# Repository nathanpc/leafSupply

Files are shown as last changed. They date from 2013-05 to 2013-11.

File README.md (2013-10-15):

leafSupply

## More Information

For more information about how this project evolved you should check out the [project blog](http://electronics.dreamintech.net/).

## Credits

This project is the work of:

 - [Nathan Campos](http://about.me/nathanpc): Everything involved with the electronics part.
 - [Narek Babajanyan](https://twitter.com/narekb): Awesome leaf icon.

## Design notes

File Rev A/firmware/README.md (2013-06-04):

# leafSupply Firmware

This is the leafSupply firmware for the [TI MSP430G2553](http://www.ti.com/lit/ds/symlink/msp430g2553.pdf) microcontroller.

## Pins

TODO: Put a pin list right here.

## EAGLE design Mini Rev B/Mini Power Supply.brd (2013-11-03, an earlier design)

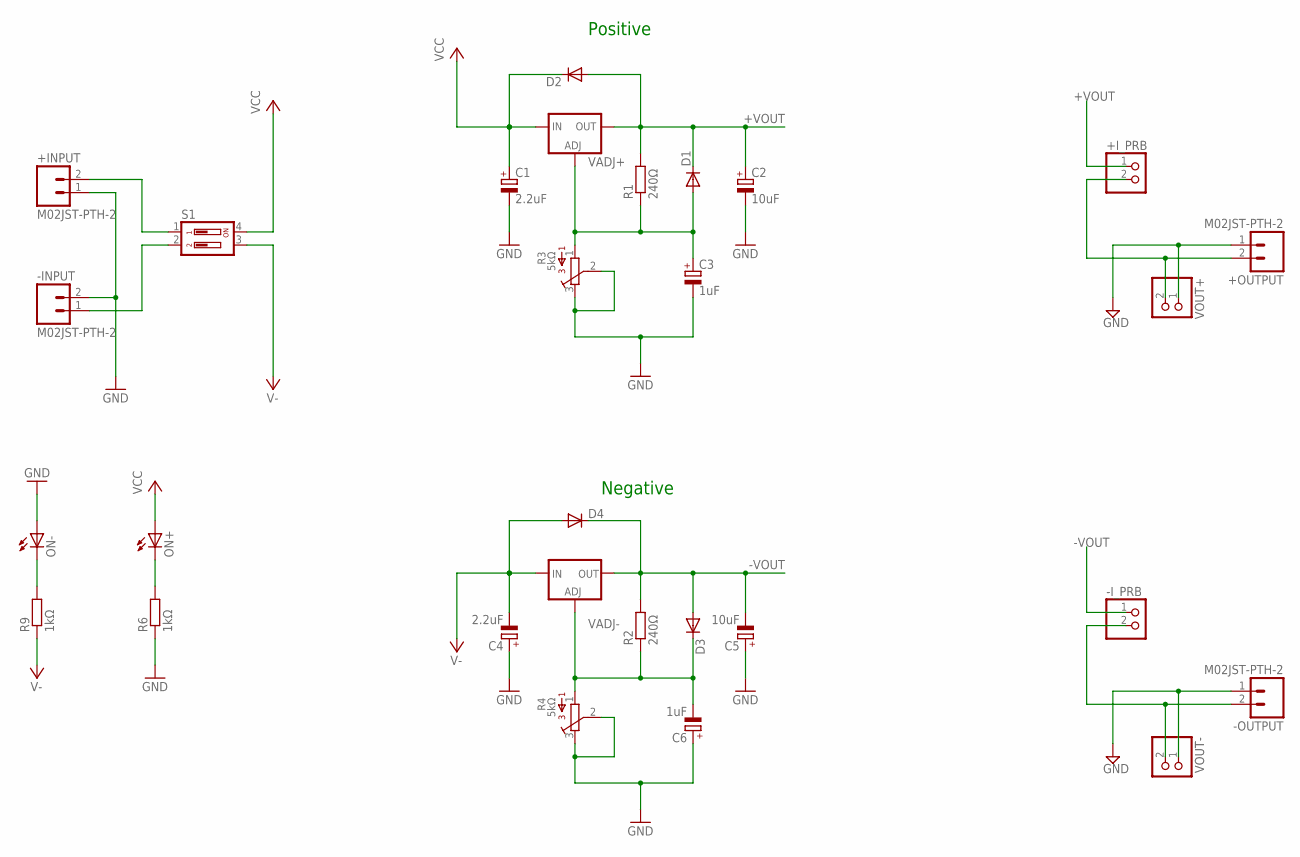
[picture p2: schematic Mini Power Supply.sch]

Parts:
+INPUT: M02JST-PTH-2; JST-2-PTH
+I_PRB: PINHD-1X2; 1X02
+OUTPUT: M02JST-PTH-2; JST-2-PTH
-INPUT: M02JST-PTH-2; JST-2-PTH
-I_PRB: PINHD-1X2; 1X02
-OUTPUT: M02JST-PTH-2; JST-2-PTH
C1, C4: 2.2uF; E2,5-6
C2, C5: 10uF; E2,5-6
C3, C6: 1uF; E2,5-6
D1, D2, D3, D4: 1N4148DO35-7; DO35-7
ON+: LEDSQR2X5; LED2X5
ON-: LEDSQR2X5; LED2X5
R1, R2: 240Ω; 0207/10
R3, R4: 5kΩ; 3386U
R6, R9: 1kΩ; 0207/10
S1: DIP02YL
VADJ+: LM317L; 317L
VADJ-: LM337L; 337L
VOUT+: PINHD-1X2; 1X02
VOUT-: PINHD-1X2; 1X02

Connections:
+VOUT: +I_PRB.1, C2.+, D1.C, D2.A, R1.2, VADJ+.2 (OUT)
-VOUT: -I_PRB.1, C5.-, D3.A, D4.C, R2.2, VADJ-.OUT
GND: +INPUT.1, +OUTPUT.1, -INPUT.2, -OUTPUT.1, C1.-, C2.-, C3.-, C4.+, C5.+, C6.+, ON-.A, R3.2, R3.3, R4.2, R4.3, R6.1, VOUT+.1, VOUT-.1
unnamed: C6.-, D3.C, R2.1, R4.1, VADJ-.ADJ
unnamed: +INPUT.2, S1.1
unnamed: C3.+, D1.A, R1.1, R3.1, VADJ+.1 (ADJ)
unnamed: ON-.K (C), R9.2
unnamed: -INPUT.1, S1.2
unnamed: ON+.K (C), R6.2
unnamed: +I_PRB.2, +OUTPUT.2, VOUT+.2
unnamed: -I_PRB.2, -OUTPUT.2, VOUT-.2
V-: C4.-, D4.A, R9.1, S1.3, VADJ-.IN
VCC: C1.+, D2.C, ON+.A, S1.4, VADJ+.3 (IN)

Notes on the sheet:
Positive
Negative

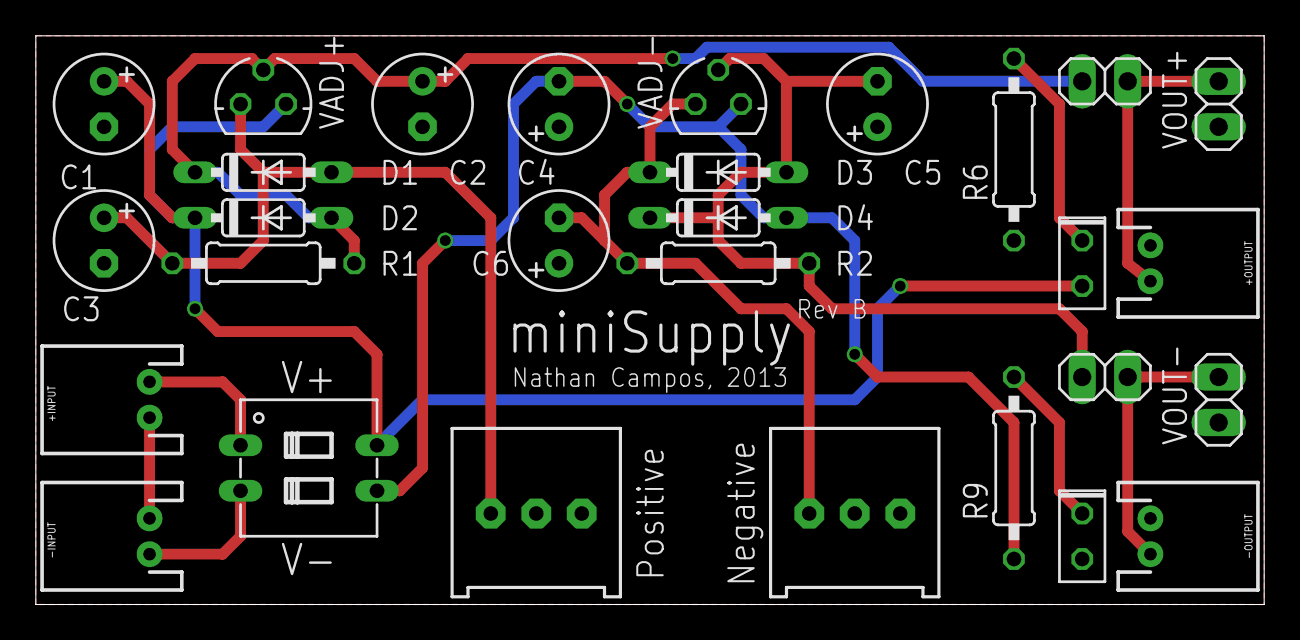
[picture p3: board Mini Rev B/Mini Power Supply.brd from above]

Board: 4 copper layers, 68.6 x 31.8 mm, 29 parts (0 on the bottom side), 13 nets.

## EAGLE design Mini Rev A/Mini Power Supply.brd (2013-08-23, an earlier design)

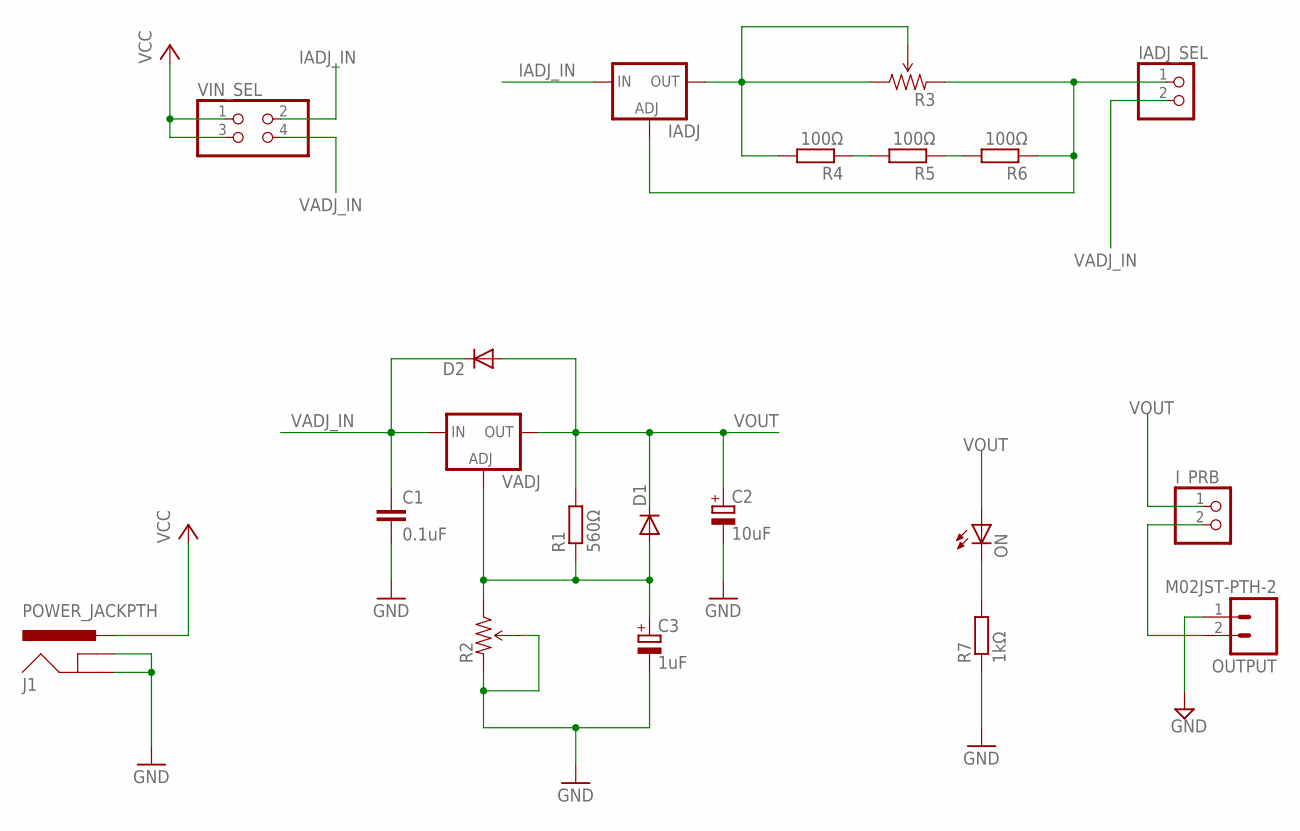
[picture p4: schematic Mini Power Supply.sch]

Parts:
C1: 0.1uF; C0805
C2: 10uF; E2,5-6
C3: 1uF; E2,5-6
D1, D2: DIODE-SOD323-W; SOD323-W
IADJ: LM317TS; 317TS
IADJ_SEL: PINHD-1X2; 1X02
I_PRB: PINHD-1X2; 1X02
J1: POWER_JACKPTH; POWER_JACK_PTH
ON: LEDCHIPLED_1206; CHIPLED_1206
OUTPUT: M02JST-PTH-2; JST-2-PTH
R1: 560Ω; R0805
R2, R3: TRIMPOT-PTH-KNOB; 3386U
R4, R5, R6: 100Ω; R0805
R7: 1kΩ; R0805
VADJ: LM317TS; 317TS
VIN_SEL: PINHD-2X2; 2X02

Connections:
GND: C1.2, C2.-, C3.-, J1.GND, J1.GNDBREAK, OUTPUT.1, R2.2 (WIPER), R2.3 (CW), R7.1
IADJ_IN: IADJ.3 (IN), VIN_SEL.2
unnamed: IADJ.2 (OUT), R3.1 (CCW), R3.2 (WIPER), R4.2
unnamed: R4.1, R5.2
unnamed: C3.+, D1.A, R1.1, R2.1 (CCW), VADJ.1 (ADJ)
unnamed: IADJ.1 (ADJ), IADJ_SEL.1, R3.3 (CW), R6.1
unnamed: R5.1, R6.2
unnamed: ON.C, R7.2
unnamed: I_PRB.2, OUTPUT.2
VADJ_IN: C1.1, D2.C, IADJ_SEL.2, VADJ.3 (IN), VIN_SEL.4
VCC: J1.PWR, VIN_SEL.1, VIN_SEL.3
VOUT: C2.+, D1.C, D2.A, I_PRB.1, ON.A, R1.2, VADJ.2 (OUT)

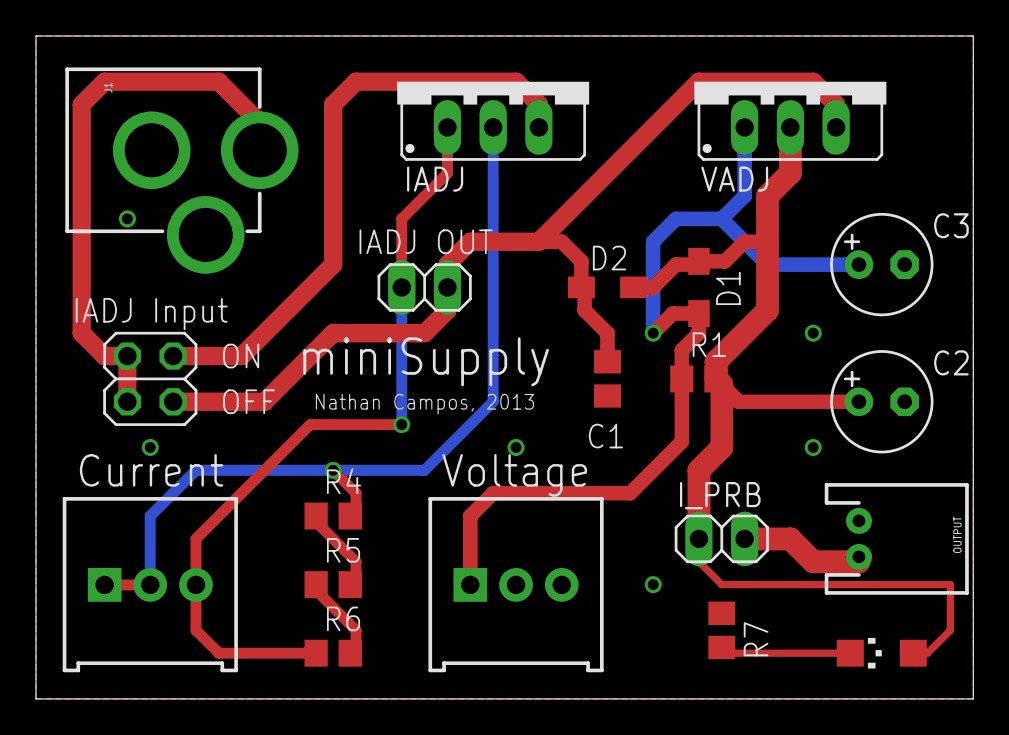
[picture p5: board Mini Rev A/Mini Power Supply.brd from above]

Board: 2 copper layers, 52.1 x 36.8 mm, 20 parts (0 on the bottom side), 12 nets.

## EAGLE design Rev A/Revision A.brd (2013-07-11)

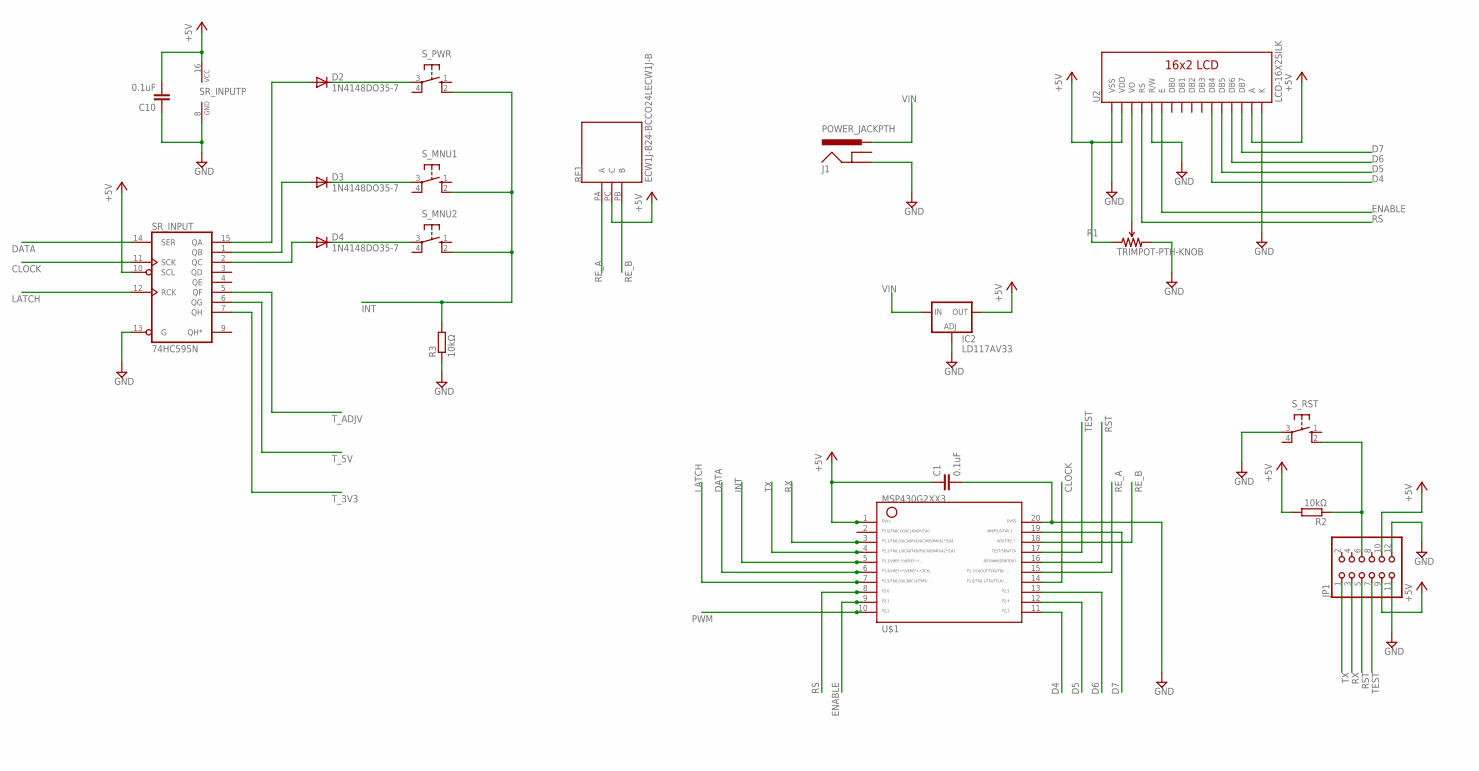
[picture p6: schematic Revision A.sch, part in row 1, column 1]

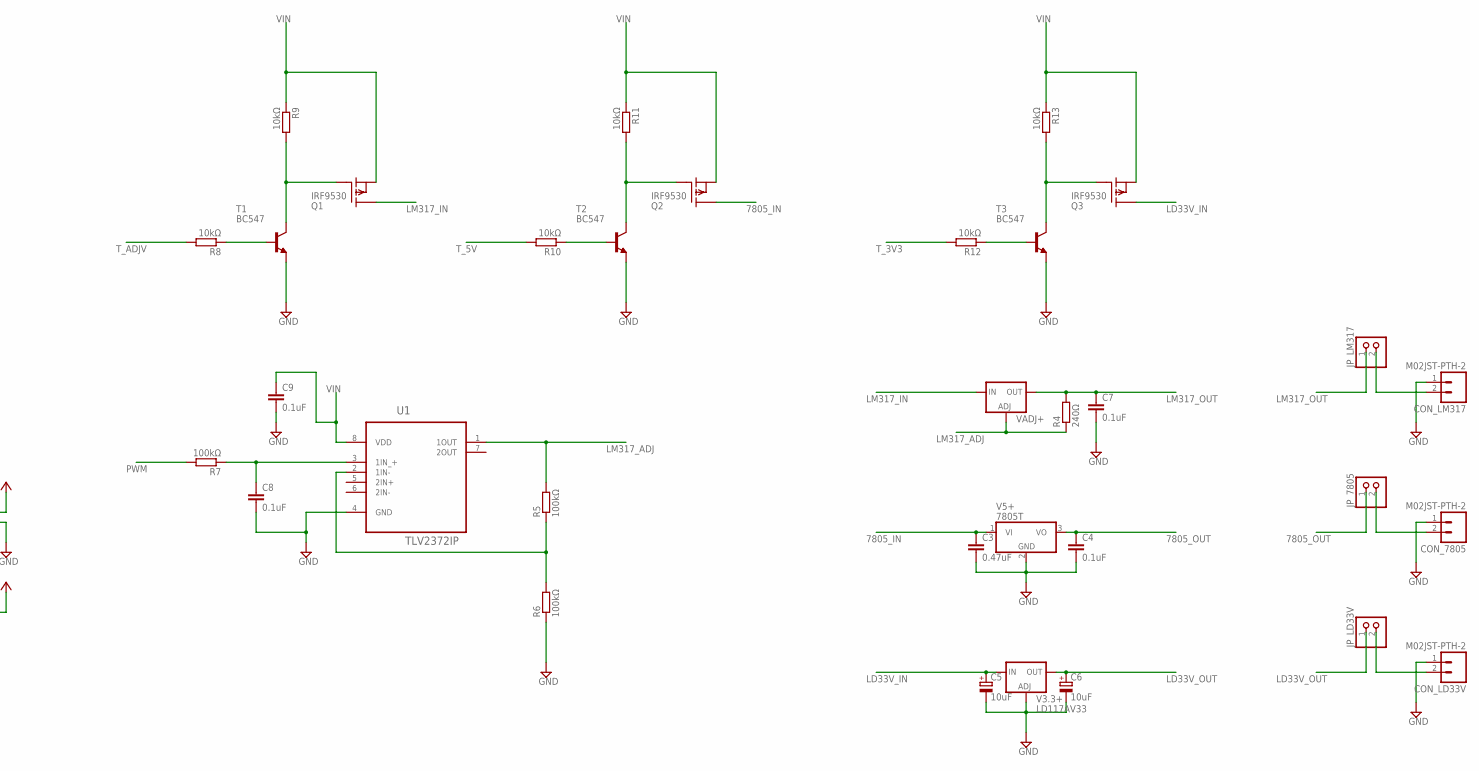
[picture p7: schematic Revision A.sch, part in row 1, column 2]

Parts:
C1, C4, C7, C8, C9, C10: 0.1uF; C025-025X050
C3: 0.47uF; C025-025X050
C5, C6: 10uF; E2,5-6
CON_7805: M02JST-PTH-2; JST-2-PTH
CON_LD33V: M02JST-PTH-2; JST-2-PTH
CON_LM317: M02JST-PTH-2; JST-2-PTH
D2, D3, D4: 1N4148DO35-7; DO35-7
IC2: LD117AV33; TO220L1
J1: POWER_JACKPTH; POWER_JACK_PTH
JP1: PINHD-2X6; 2X06
JP_7805: PINHD-1X2; 1X02
JP_LD33V: PINHD-1X2; 1X02
JP_LM317: PINHD-1X2; 1X02
Q1, Q2, Q3: IRF9530; TO220
R1: TRIMPOT-PTH-KNOB; 3386U
R2, R3, R8, R9, R10, R11, R12, R13: 10kΩ; 0207/10
R4: 240Ω; 0207/10
R5, R6, R7: 100kΩ; 0207/10
RE1: ECW1J-B24-BCCO24LECW1J-B; ECW1J-B
SR_INPUT: 74HC595N; DIL16
S_MNU1, S_MNU2: 10-XX; B3F-10XX
S_PWR: 10-XX; B3F-10XX
S_RST: 10-XX; B3F-10XX
T1, T2, T3: BC547; TO92
U1: TLV2372IP; DIP254P762X508-8
U2: LCD-16X2SILK; LCD-16X2
U$1: G2XX3---N20; N20
V3.3+: LD117AV33; TO220L1
V5+: 7805T; TO220H
VADJ+: LM317TL; 317TL

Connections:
7805_IN: C3.1, Q2.2 (D), V5+.1 (VI)
7805_OUT: C4.1, JP_7805.1, V5+.3 (VO)
+5V: C1.1, C10.2, IC2.2 (OUT), JP1.9, JP1.10, R1.1 (CCW), R2.2, RE1.PC (C), SR_INPUT.10 (SCL), SR_INPUT.16 (VCC), U2.2 (VDD), U2.15 (A), U$1.1
CLOCK: SR_INPUT.11 (SCK), U$1.14
D4: U2.11 (DB4), U$1.11
D5: U2.12 (DB5), U$1.12
D6: U2.13 (DB6), U$1.13
D7: U2.14 (DB7), U$1.19
DATA: SR_INPUT.14 (SER), U$1.6
ENABLE: U2.6 (E), U$1.9
GND: C1.2, C3.2, C4.2, C5.-, C6.-, C7.2, C8.2, C9.2, C10.1, CON_7805.1, CON_LD33V.1, CON_LM317.1, IC2.1 (ADJ), J1.GND, JP1.11, JP1.12, R1.3 (CW), R3.1, R6.1, SR_INPUT.8 (GND), SR_INPUT.13 (G), S_RST.3, T1.1 (E), T2.1 (E), T3.1 (E), U1.4 (GND), U2.1 (VSS), U2.5 (R/W), U2.16 (K), U$1.20, V3.3+.1 (ADJ), V5+.2 (GND)
INT: R3.2, S_MNU1.2 (S1), S_MNU2.2 (S1), S_PWR.2 (S1), U$1.5
LATCH: SR_INPUT.12 (RCK), U$1.7
LD33V_IN: C5.+, Q3.2 (D), V3.3+.3 (IN)
LD33V_OUT: C6.+, JP_LD33V.1, V3.3+.2 (OUT)
LM317_ADJ: R4.1, R5.2, U1.1 (1OUT), VADJ+.1 (ADJ)
LM317_IN: Q1.2 (D), VADJ+.3 (IN)
LM317_OUT: C7.1, JP_LM317.1, R4.2, VADJ+.2 (OUT)
unnamed: R1.2 (WIPER), U2.3 (VO)
unnamed: D2.C, S_PWR.3
unnamed: JP1.6, R2.1, S_RST.2 (S1)
unnamed: D3.C, S_MNU1.3
unnamed: D4.C, S_MNU2.3
unnamed: R5.1, R6.2, U1.2 (1IN-)
unnamed: C8.1, R7.1, U1.3 (1IN_+)
unnamed: R8.1, T1.2 (B)
unnamed: Q1.1 (G), R9.2, T1.3 (C)
unnamed: R10.1, T2.2 (B)
unnamed: D3.A, SR_INPUT.1 (QB)
unnamed: Q2.1 (G), R11.2, T2.3 (C)
unnamed: R12.1, T3.2 (B)
unnamed: Q3.1 (G), R13.2, T3.3 (C)
unnamed: CON_LM317.2, JP_LM317.2
unnamed: D4.A, SR_INPUT.2 (QC)
unnamed: D2.A, SR_INPUT.15 (QA)
unnamed: CON_7805.2, JP_7805.2
unnamed: CON_LD33V.2, JP_LD33V.2
PWM: R7.2, U$1.10
RE_A: RE1.PA (A), U$1.15
RE_B: RE1.PB (B), U$1.18
RS: U2.4 (RS), U$1.8
RST: JP1.5, U$1.16
RX: JP1.3, U$1.3
TEST: JP1.7, U$1.17
TX: JP1.1, U$1.4
T_3V3: R12.2, SR_INPUT.7 (QH)
T_5V: R10.2, SR_INPUT.6 (QG)
T_ADJV: R8.2, SR_INPUT.5 (QF)
VIN: C9.1, IC2.3 (IN), J1.PWR, Q1.3 (S), Q2.3 (S), Q3.3 (S), R9.1, R11.1, R13.1, U1.8 (VDD)

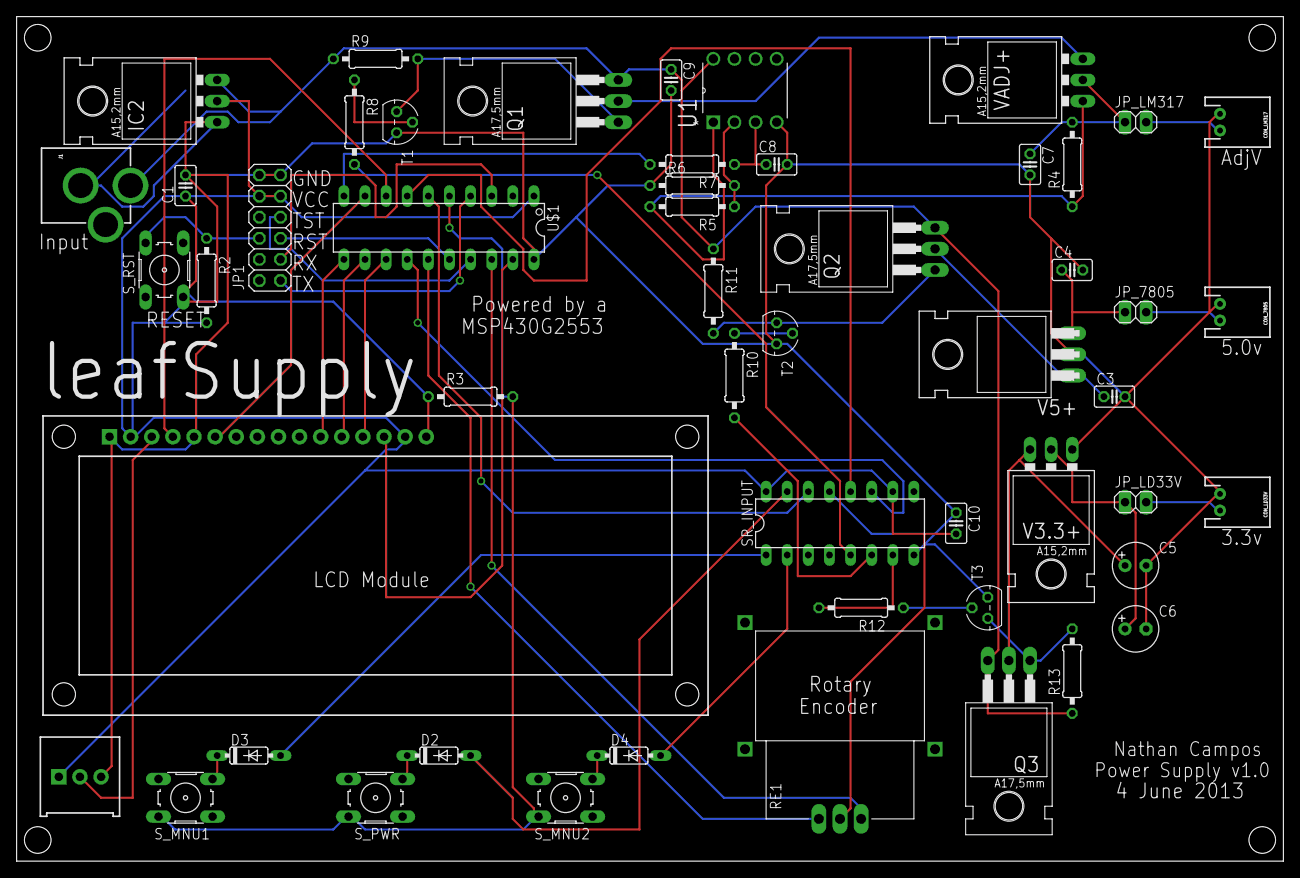
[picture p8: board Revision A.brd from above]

Board: 2 copper layers, 152.4 x 101.6 mm, 52 parts (0 on the bottom side), 49 nets.

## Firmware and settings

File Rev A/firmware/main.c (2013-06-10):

/**
 *	main.c
 *	leafSupply firmware for the MSP430G2553 microcontroller.
 *
 *	@author Nathan Campos <nathanpc@dreamintech.net>
 */

#include <msp430g2553.h>
#include <stdio.h>
#include <string.h>

#include "boolean.h"
#include "delay.h"
#include "bitio.h"
#include "ftoa.h"

#include "74HC595.h"
#include "rotary_encoder.h"
#include "HD44780.h"
#include "voltage_regulators.h"

// Interrupt pins.
#define BT_INT   BIT3
#define RE_A_INT BIT7
#define RE_B_INT BIT7

// Other pins.
#define PWM_PIN  BIT2

// Screen codes.
#define HOME_SCREEN 0

unsigned char shift_default_on = 0b11111000;

void print_voltage();
void print_vreg_state();
void print_screen(const unsigned int title);
void switch_vreg();

void setup_pwm();
void setup_interrupts();
void handle_re_rotation();
void handle_bt_press(unsigned int bt);

/**
 *	Where the magic starts.
 */
void main() {
	WDTCTL = WDTPW + WDTHOLD;  // Stop watchdog timer.
	//BCSCTL1 = CALBC1_1MHZ;     // Set range.
	//DCOCTL = CALDCO_1MHZ;      // SMCLK = DCO = 1MHz
	//BCSCTL2 &= ~(DIVS_3);

	// Setup the PWM stuff, ADC, and interrupts.
	setup_pwm();
	setup_interrupts();
	_BIS_SR(GIE);  // TODO: Do (LPMX + GIE) for low-power + interrupts.
	//__enable_interrupt();

	// Initialize the shift register driver.
	shift_register_setup();
	shift_out(shift_default_on);
	
	// Setup the LCD driver.
	lcd_init(TRUE, TRUE);

	// Initilalize the voltage regulator driver.
	vreg_init();

	// Go to the home screen.
	print_screen(HOME_SCREEN);

	while (TRUE) {
	}
}

/**
 *	Setup the interrupts stuff.
 */
void setup_interrupts() {
	P1DIR &= ~(BT_INT + RE_A_INT);
	P2DIR &= ~RE_B_INT;
	P2SEL &= ~RE_B_INT;  // Turn XOUT into P2.7

	P1IES &= ~(BT_INT + RE_A_INT);  // Set the interrupt to be from LOW to HIGH.
	P1IFG &= ~(BT_INT + RE_A_INT);  // P1.3 and P1.7 IFG cleared
	P1IE |= (BT_INT + RE_A_INT);    // Set P1.3 and P1.7 as interrupt.
}

/**
 *	Setup the PWM stuff.
 */
void setup_pwm() {
	P2DIR |= PWM_PIN;
	P2SEL |= PWM_PIN;      // Set P2.2 to TA1.1

	TA1CCR0  = 100 - 1;    // PWM period.
	TA1CCTL1 = OUTMOD_7;   // CCR1 Reset/Set.
	TA1CCR1  = 0;          // CCR1 PWM duty cycle.
	TA1CTL   = TASSEL_2 + MC_1;
}

/**
 *	Prints a "screen".
 *
 *	@param title The screen you want to display.
 */
void print_screen(const unsigned int title) {
	lcd_clear();

	switch (title) {
		case HOME_SCREEN:
			// Example:
			// +----------------+
			// |LM317       7.8V|
			// |             OFF|
			// +----------------+
			lcd_print(vregs.list[vregs.curr_onscreen], 0, 0);
			print_voltage();
			print_vreg_state();
			break;
	}
}

/**
 *	Cycles between the available voltage regulators.
 */
void switch_vreg() {
	if (vregs.curr_onscreen < 2) {
		vregs.curr_onscreen++;
	} else  {
		vregs.curr_onscreen = 0;
	}

	print_screen(HOME_SCREEN);
}

/**
 *	Prints the current voltage regulator state. (ON/OFF)
 */
void print_vreg_state() {
	if (vregs.state[vregs.curr_onscreen]) {
		lcd_print(" ON", 1, 13);
	} else {
		lcd_print("OFF", 1, 13);
	}
}

/**
 *	Prints the voltage that should be going out of the voltage regulator.
 */
void print_voltage() {
	char vstr[10];
	if (vregs.curr_onscreen != LM317) {
		ftoa(vstr, vregs.voltages[vregs.curr_onscreen], 1);
		strcat(vstr, "V");
	} else {
		sprintf(vstr, "  %d%%", vregs.pwm[vregs.curr_onscreen]);
	}

	lcd_print(vstr, 0, 16 - strlen(vstr));
}


//
//	Handlers
//

/**
 *	Handles a button press.
 *
 *	@param bt A button.
 */
void handle_bt_press(unsigned int bt) {
	switch (bt) {
		case 0:  // S_PWR
			lcd_print("S_PWR Pressed", 1, 0);
			break;
		case 1:  // S_MNU1
			// Change voltage regulator.
			//lcd_print("S_MNU1 Pressed", 1, 0);
			switch_vreg();
			break;
		case 2:  // S_MNU2
			// Toogle ON/OFF
			//lcd_print("S_MNU2 Pressed", 1, 0);
			toggle_power(&shift_default_on, vregs.curr_onscreen);
			print_vreg_state();
			break;
		default:
			lcd_print("WTF you just pressed?!", 1, 0);
			break;
	}
}

/**
 *	Handles a rotary encoder rotation.
 */
void handle_re_rotation() {
	if (rotary_encoder_rotation() == 1) {
		vreg_set_voltage(TRUE);
		print_voltage();
	} else if (rotary_encoder_rotation() == -1) {
		vreg_set_voltage(FALSE);
		print_voltage();
	}
}


//
//	Interrupts
//

/**
 *	Interrupt service routine for P1.
 */
#pragma vector = PORT1_VECTOR
__interrupt void P1_ISR() {
	switch(P1IFG & (BT_INT + RE_A_INT)) {
		case BT_INT:
			// Handle the input array interrupt.
			P1IFG &= ~BT_INT;  // P1.3 IFG cleared.
			
			// Loops through the buttons.
			for (unsigned int i = 0; i < 4; i++) {
				unsigned char tmp[] = { 0b10000000, 0b01000000, 0b00100000, 0b00010000 };
				tmp[i] |= (shift_default_on & 0b00001111);

				// Check if the button was pressed.
				shift_out(tmp[i]);
				if ((P1IN & BT_INT) == BT_INT) {
					handle_bt_press(i);
				}
			}
			
			unsigned char lst = shift_default_on;
			//lst |= leds;
			shift_out(lst);
			
			while ((P1IN & BT_INT) == BT_INT) {}
			break;
		case RE_A_INT:
			// Handle the rotary encoder A interrupt.
			P1IFG &= ~RE_A_INT;  // P1.7 IFG cleared.
			handle_re_rotation();
		default:
			P1IFG = 0;
			break;
	}

	P1IFG = 0;
}

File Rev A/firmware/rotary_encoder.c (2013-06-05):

/**
 *	rotary_encoder.h
 *	A rotary encoder driver for the MSP430G2553.
 *
 *	@author Nathan Campos <nathanpc@dreamintech.net>
 */

#include <msp430g2553.h>
#include <stdint.h>

#include "boolean.h"
#include "rotary_encoder.h"
#include "delay.h"
#include "bitio.h"

// Define the rotary encoder pins.
#define A BIT7
#define B BIT7

/**
 * Check if the rotary encoder was rotated clockwise.
 * 
 * @return TRUE if it was rotated clockwise, FALSE if it was rotate counter clockwise.
 */
int8_t rotary_encoder_rotation() {
	/*if (((P1IN & A) == A) && ((P2IN & B) == 0)) {
		// Wait until the pulses finish doing their thing.
		while (((P1IN & A) == A) && ((P2IN & B) == 0)) {}
		while ((P2IN & B) == B) {}

		// It was rotated clockwise.
		return 1;
	} else if (((P2IN & B) == B) && ((P1IN & A) == 0)) {
		// Wait until the pulses finish doing their thing.
		while (((P2IN & B) == B) && ((P1IN & A) == 0)) {}
		while ((P1IN & A) == A) {}

		// It was rotated counter clockwise.
		return -1;
	}*/

	if ((P2IN & B) == B) {
		return -1;
	} else {
		return 1;
	}

	return 0;
}

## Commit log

2013-05-24 First crappy draft stuff
    [First Draft.sch]
2013-05-26 Removed the digital potentiometer in favor of PWM control to use less pins
2013-05-26 Started working in the microcontroller part
    [Microcontroller Draft.sch]
2013-05-30 Oops, looks like my pin count was wrong
2013-05-30 Added the Output Logic schematic
    [Microcontroller Draft.sch, Output Logic.sch]
2013-05-30 Added a truth table to the output logic schematic
    [Output Logic.sch]
2013-06-01 Started working in the new Shift Register oriented design
    [Shift Registers.sch]
2013-06-01 Finished the shift register oriented design schematic
    [Shift Registers.sch]
2013-06-01 Added some decoupling capacitors
    [Shift Registers.sch]
2013-06-05 Improved the shift register design since we are going to use a rotary encoder
    [Shift Registers.sch]
2013-06-06 Implemented a line/col print function
2013-06-06 Started working in the output logic
    [Output.sch, Shift Registers.sch]
2013-06-08 Working with PWM
2013-06-09 Finished all the voltage control stuff
2013-06-10 Removed a button
    [Shift Registers.sch]
2013-06-10 Finished the output schematic
    [Output.sch]
2013-06-10 Removed all the outdated crappy microcontroller drafts
    [Microcontroller Draft.sch, Output Logic.sch]
2013-06-10 Added the LCD schematic
    [LCD.sch, User Input.sch]
2013-06-11 Finished the individual schematics
    [Microcontroller.sch, Output.sch, User Input.sch]
2013-06-11 Fixed some errors
    [Output.sch, User Input.sch]
2013-06-11 Used the awesome SparkFun LCD footprint
    [LCD.sch]
2013-06-11 Created a custom library for the rotary encoder footprint
2013-06-11 Added the rotary encoder to the mix
    [Microcontroller.sch, User Input.sch]
2013-06-11 Added the full schematic for Rev A
    [Revision A.sch]
2013-06-11 Made things look nicer for print
    [Revision A.sch]
2013-06-11 Renamed the Microcontroller Draft folder to Rev A
    [LCD.sch, Microcontroller.sch, Output.sch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]
2013-06-14 Added the input barrel jack
    [Microcontroller.sch, Revision A.sch]
2013-06-14 Board designed
    [Revision A.brd]
2013-06-14 Finished the silkscreen stuff
    [Revision A.brd]
2013-06-14 Fixed the RESET pin connection
    [Revision A.brd, Revision A.sch]
2013-07-11 Fixed the voltage regulator for the MCU
    [Revision A.brd, Revision A.sch]
2013-07-11 Moved everything related to the Rev A to its folder so we can start working on Rev B
    [Revision A.brd, Revision A.sch]
2013-08-23 Designed a mini version
    [Mini Power Supply.brd, Mini Power Supply.sch]
2013-09-08 Started working on Rev B of the mini
    [Mini Power Supply.brd, Mini Power Supply.sch]
2013-09-08 Changed the input to a JST and connected the ON LED to VCC
    [Mini Power Supply.brd, Mini Power Supply.sch]
2013-09-10 Finished most of the new revision
    [Mini Power Supply.brd, Mini Power Supply.sch]
2013-09-13 Started working on the negative rail for the mini Rev B
    [Mini Power Supply.brd, Mini Power Supply.sch]
2013-09-13 Finished the negative rail
    [Mini Power Supply.brd, Mini Power Supply.sch]
2013-10-15 Redid the Mini Rev B
    [Mini Power Supply.brd, Mini Power Supply.sch]
2013-10-15 Finished the layout for Mini Rev B
    [Mini Power Supply.brd, Mini Power Supply.sch]
2013-11-03 Fixed the negative voltage regulator
    [Mini Power Supply.brd, Mini Power Supply.sch]
2013-11-10 Started working on Mini Rev C
    [Mini Power Supply.sch]

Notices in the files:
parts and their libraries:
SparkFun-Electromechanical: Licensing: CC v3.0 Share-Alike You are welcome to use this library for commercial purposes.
